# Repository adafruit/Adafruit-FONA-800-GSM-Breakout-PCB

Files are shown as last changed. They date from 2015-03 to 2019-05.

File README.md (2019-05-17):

# Adafruit FONA 800 GSM Breakout PCBs
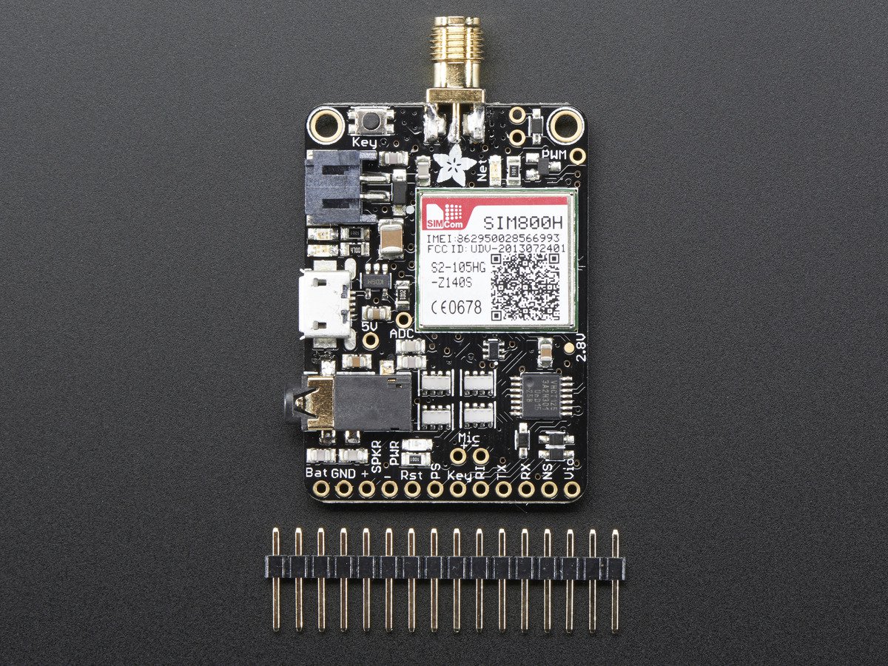
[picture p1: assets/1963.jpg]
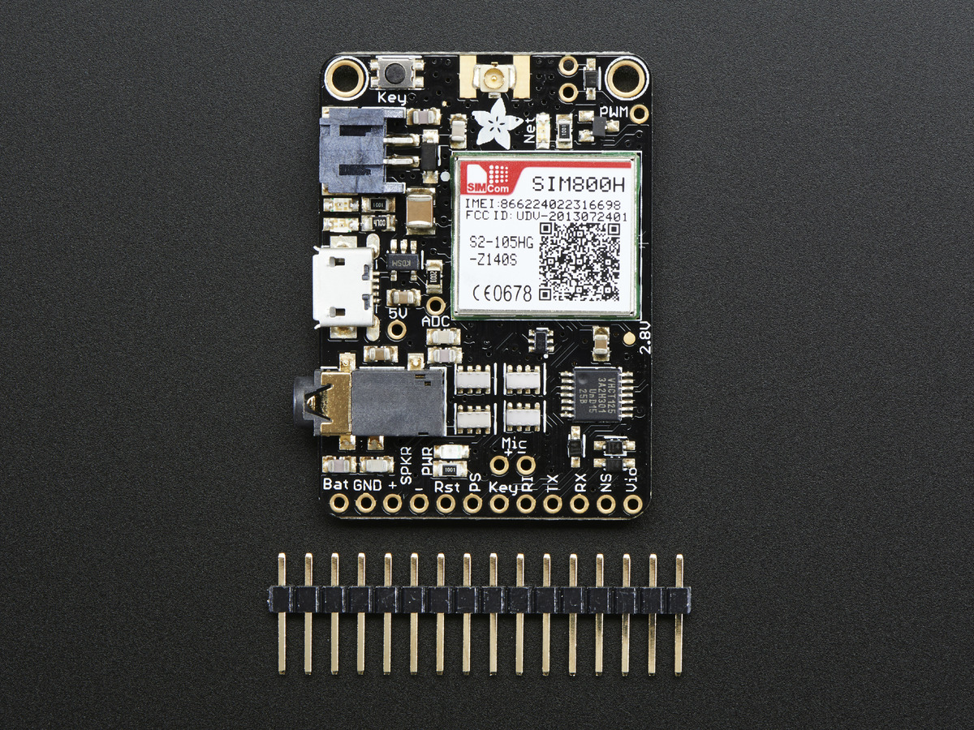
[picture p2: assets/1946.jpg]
&nbsp; <br />
Click to purchase from the Adafruit Shop:
- [Adafruit FONA - Mini Cellular GSM Breakout - SMA Version - v1](https://www.adafruit.com/product/1963)
- [Adafruit FONA - Mini Cellular GSM Breakout uFL Version](https://www.adafruit.com/product/1946)

This module measures only 1.75"x1.25" but packs a surprising amount of technology into its little frame. At the heart is a GSM cellular module (we use the latest SIM800) the size of a postage stamp. This module can do just about everything. One version has an SMA connector, the other has a uFL connector.

Quad-band 850/900/1800/1900MHz - connect onto any global GSM network with any 2G SIM (in the USA, T-Mobile is suggested)
- Make and receive voice calls using a headset OR an external 8Ω speaker + electret microphone
- Send and receive SMS messages
- Send and receive GPRS data (TCP/IP, HTTP, etc.)
- Scan and receive FM radio broadcasts (yeah, we don't exactly know why this was included but it works really well)
- PWM/Buzzer vibrational motor control
- AT command interface with "auto baud" detection

PCB files for the Adafruit FONA 800 GSM Cellular Breakouts. The format is EagleCAD schematic and board layout
- https://www.adafruit.com/products/1963
- https://www.adafruit.com/products/1946

### License

Adafruit invests time and resources providing this open source design, please support Adafruit and open-source hardware by purchasing products from [Adafruit](https://www.adafruit.com)!

All text above must be included in any redistribution

Designed by Limor Fried/Ladyada for Adafruit Industries.
Creative Commons Attribution/Share-Alike, all text above must be included in any redistribution. 
See license.txt for additional information.

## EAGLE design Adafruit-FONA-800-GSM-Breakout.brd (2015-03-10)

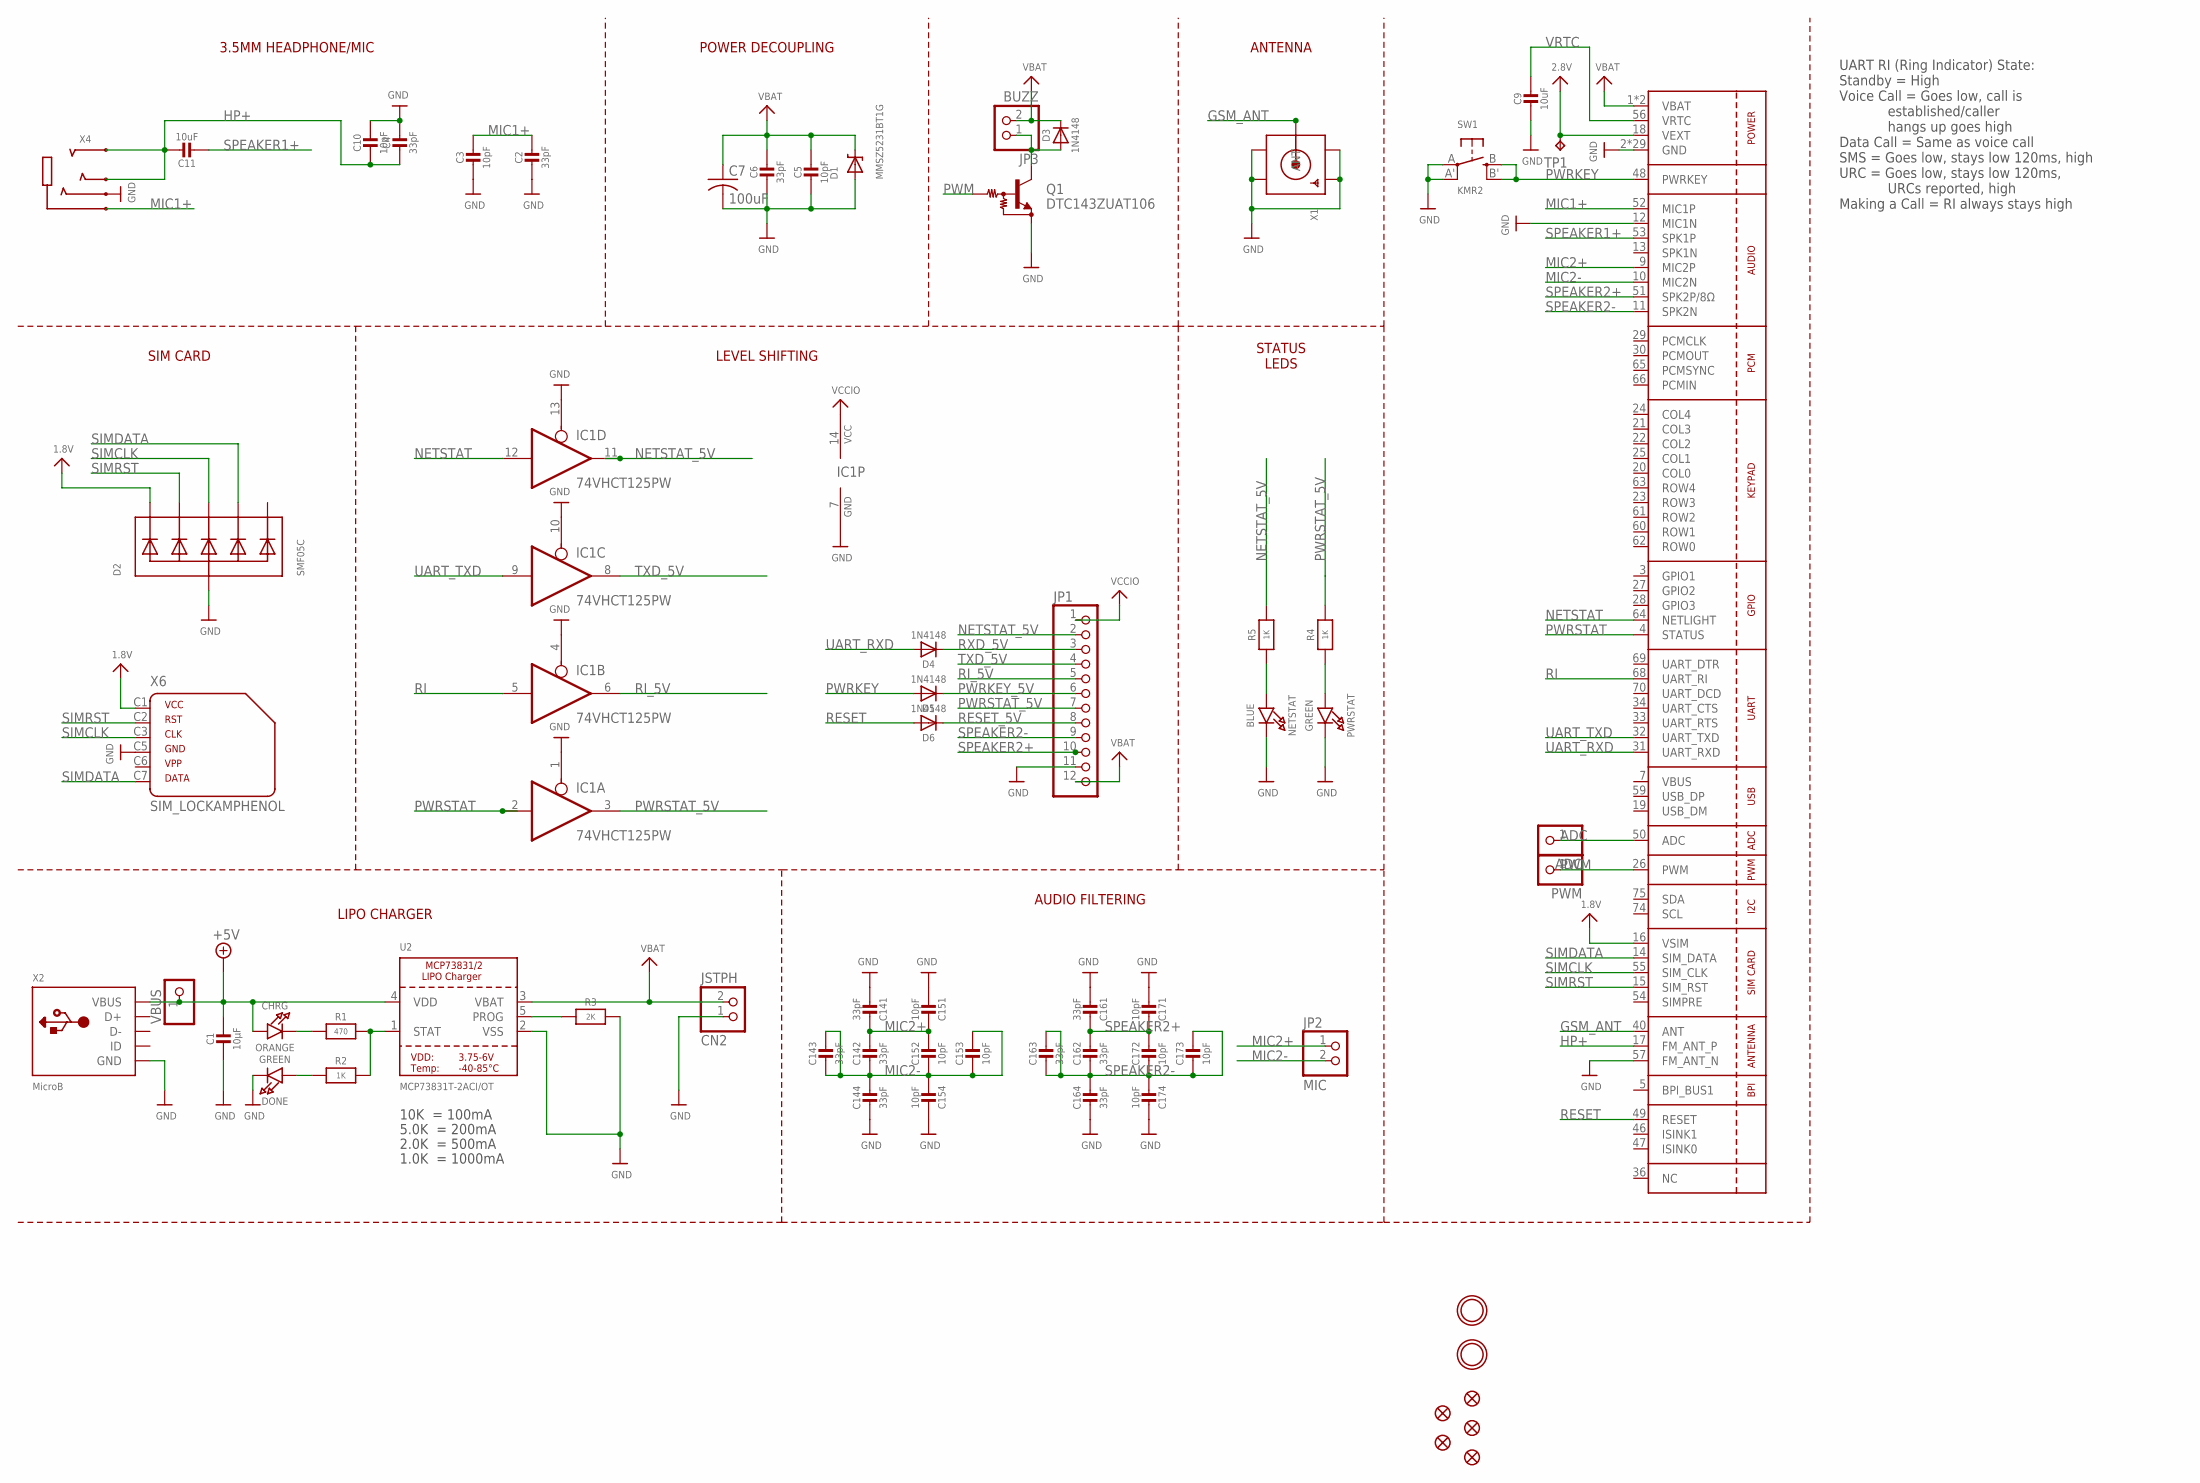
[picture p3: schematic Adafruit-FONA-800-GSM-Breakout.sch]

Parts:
ADC: PINHD-1X1CB; 1X01-CLEANBIG
C1: 10µF; 0805-NO
C2, C4, C6: 33pF; 0805-NO
C3, C5, C10: 10pF; 0805-NO
C7: 100uF; C1210
C9, C11: 10uF; 0805-NO
C14, C16: 33pF; RESPACK_4X0603
C15, C17: 10pF; RESPACK_4X0603
CHRG: ORANGE; CHIPLED_0805_NOOUTLINE
CN2: JSTPH; JSTPH2
D1: MMSZ5231BT1G; SOD-123
D2: SMF05C; SOT363
D3, D4, D5, D6: 1N4148; SOD-323
DONE: GREEN; CHIPLED_0805_NOOUTLINE
FID1, FID2, FID3, FID4, FID5: FIDUCIAL""; FIDUCIAL_1MM
IC1: 74VHCT125PW; TSSOP14
JP1: PINHD-1X12-CB; 1X12-CB
JP2: MIC; 1X02_ROUND
JP3: BUZZ; 1X02_ROUND
NETSTAT: BLUE; CHIPLED_0805_NOOUTLINE
PWM: PINHD-1X1CB; 1X01-CLEANBIG
PWRSTAT: GREEN; CHIPLED_0805_NOOUTLINE
Q1: DTC143ZUAT106; SC59-BEC
R1: 470; 0805-NO
R2, R4, R5: 1K; 0805-NO
R3: 2K; 0805-NO
SW1: KMR2; BTN_KMR2_4.6X2.8
TP1: TPTP11R; TP11R
U1: SIM800H/L; SIM800L
U2: MCP73831T-2ACI/OT; SOT23-5
U$33, U$34: MOUNTINGHOLE2.5; MOUNTINGHOLE_2.5_PLATED
VBUS: PINHD-1X1CB; 1X01-CLEANBIG
X1: SMACONNECTOR_EDGE_UFL; SMA_EDGELAUNCH_UFL
X2: MicroB; 4UCONN_20329
X4: AUDIO_3.5MMJACK_4POL; 4UCONN_18510
X6: SIM_LOCKAMPHENOL; C707_10M006_512_2

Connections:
1.8V: D2.1 (C1), U1.16 (VSIM), X6.C1 (1)
2.8V: TP1.TP, U1.18 (VEXT)
+5V: C1.1, CHRG.A, U2.4 (VDD), VBUS.1, X2.VBUS
ADC: ADC.1, U1.50 (ADC)
GND: C1.2, C2.2, C3.2, C4.1, C5.2, C6.2, C7.2, C9.2, C10.1, C14.5 (2), C14.8 (2), C15.4 (1), C15.8 (2), C16.5 (2), C16.8 (2), C17.4 (1), C17.8 (2), CN2.1, D1.A, D2.2 (A), DONE.C, IC1.1 (OE), IC1.4 (OE), IC1.7 (GND), IC1.10 (OE), IC1.13 (OE), JP1.11, NETSTAT.C, PWRSTAT.C, Q1.E, R3.2, SW1.A, SW1.A' (P1), U1.2 (GND), U1.6 (GND), U1.8 (GND), U1.12 (MIC1N), U1.35 (GND), U1.37 (GND), U1.38 (GND), U1.39 (GND), U1.41 (GND), U1.43 (GND), U1.44 (GND), U1.45 (GND), U1.57 (FM_ANT_N), U1.58 (GND), U1.67 (GND), U1.71 (GND), U1.72 (GND), U1.73 (GND), U1.76 (GND), U1.77 (GND), U1.78 (GND), U1.79 (GND), U1.80 (GND), U1.81 (GND), U1.82 (GND), U1.83 (GND), U1.84 (GND), U1.85 (GND), U1.86 (GND), U1.87 (GND), U1.88 (GND), U2.2 (VSS), X1.GND@1 (GND1), X1.GND@2 (GND2), X1.GND@3 (GND3), X1.GND@4 (GND4), X2.BASE@1 (GND), X2.BASE@2 (GND), X2.GND, X2.SPRT@1 (GND), X2.SPRT@2 (GND), X2.SPRT@3 (GND), X2.SPRT@4 (GND), X4.4-INNER_SLEEVE (RING1), X6.C5 (4)
GSM_ANT: U1.40 (ANT), X1.P (ANT)
HP+: C4.2, C10.2, C11.1, U1.17 (FM_ANT_P), X4.2-TIP (RING3), X4.3-OUTER_SLEEVE (RING2)
MIC1+: C2.1, C3.1, U1.52 (MIC1P), X4.1-GND (TIP)
MIC2+: C14.1, C14.2 (1), C15.1, C15.2 (1), JP2.1, U1.9 (MIC2P)
MIC2-: C14.3 (1), C14.4 (1), C14.6 (2), C14.7 (2), C15.3 (1), C15.5 (2), C15.6 (2), C15.7 (2), JP2.2, U1.10 (MIC2N)
unnamed: CHRG.C, R1.1
unnamed: R1.2, R2.2, U2.1 (STAT)
unnamed: PWRSTAT.A, R4.1
unnamed: R3.1, U2.5 (PROG)
unnamed: DONE.A, R2.1
unnamed: NETSTAT.A, R5.1
unnamed: D3.A, JP3.1, Q1.C
NETSTAT: IC1.12 (I), U1.64 (NETLIGHT)
NETSTAT_5V: IC1.11 (O), JP1.2, R5.2
PWM: PWM.1, Q1.B, U1.26 (PWM)
PWRKEY: D5.A, SW1.B (S), SW1.B' (S1), U1.48 (PWRKEY)
PWRKEY_5V: D5.C, JP1.6
PWRSTAT: IC1.2 (I), U1.4 (STATUS)
PWRSTAT_5V: IC1.3 (O), JP1.7, R4.2
RESET: D6.A, U1.49 (RESET)
RESET_5V: D6.C, JP1.8
RI: IC1.5 (I), U1.68 (UART_RI)
RI_5V: IC1.6 (O), JP1.5
RXD_5V: D4.C, JP1.3
SIMCLK: D2.4 (C3), U1.55 (SIM_CLK), X6.C3 (3)
SIMDATA: D2.5 (C4), U1.14 (SIM_DATA), X6.C7 (6)
SIMRST: D2.3 (C2), U1.15 (SIM_RST), X6.C2 (2)
SPEAKER1+: C11.2, U1.53 (SPK1P)
SPEAKER2+: C16.1, C16.2 (1), C17.1, C17.2 (1), JP1.10, U1.51 (SPK2P/8Ω)
SPEAKER2-: C16.3 (1), C16.4 (1), C16.6 (2), C16.7 (2), C17.3 (1), C17.5 (2), C17.6 (2), C17.7 (2), JP1.9, U1.11 (SPK2N)
TXD_5V: IC1.8 (O), JP1.4
UART_RXD: D4.A, U1.31 (UART_RXD)
UART_TXD: IC1.9 (I), U1.32 (UART_TXD)
VBAT: C5.1, C6.1, C7.1, CN2.2, D1.C, D3.C, JP1.12, JP3.2, U1.1 (VBAT), U1.42 (VBAT), U2.3 (VBAT)
VBUS: U1.7 (VBUS)
VCCIO: IC1.14 (VCC), JP1.1
VRTC: C9.1, U1.56 (VRTC)

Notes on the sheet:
10K = 100mA
5.0K = 200mA
2.0K = 500mA
1.0K = 1000mA
UART RI (Ring Indicator) State: Standby = High Voice Call = Goes low, call is established/caller hangs up goes high Data Call = Same as voice call SMS = Goes low, stays low 120ms, high URC = Goes low, stays low 120ms, URCs reported, high Making a Call = RI always stays high
ANTENNA
POWER DECOUPLING
3.5MM HEADPHONE/MIC
SIM CARD
LEVEL SHIFTING
LIPO CHARGER
AUDIO FILTERING
STATUS LEDS

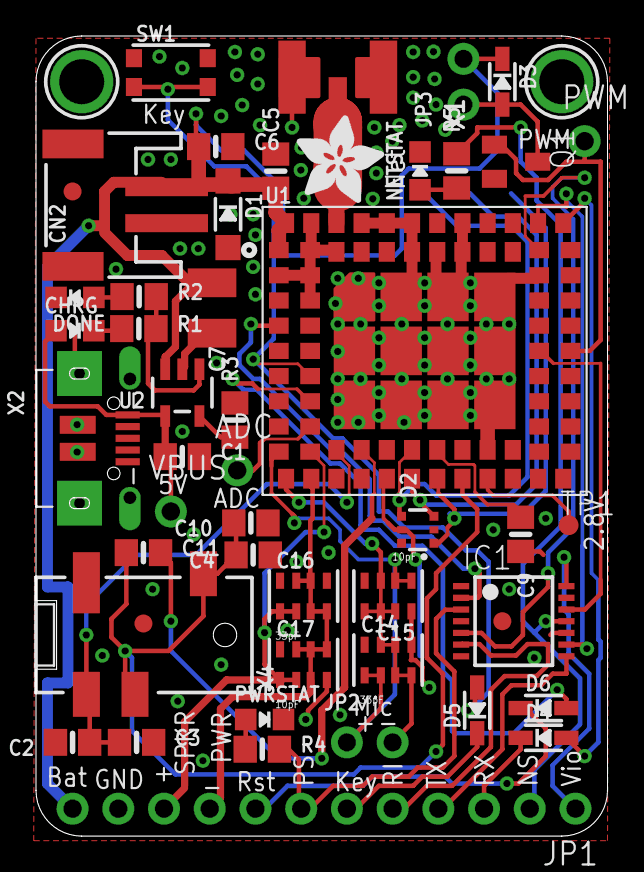
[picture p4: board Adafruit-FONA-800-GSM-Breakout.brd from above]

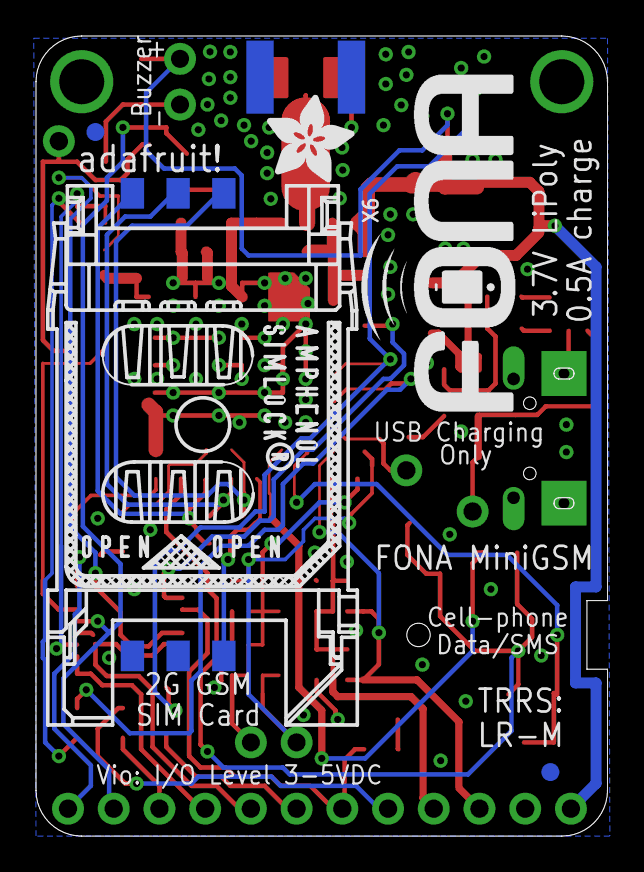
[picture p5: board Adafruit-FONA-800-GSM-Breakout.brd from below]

Board: 2 copper layers, 31.8 x 44.5 mm, 56 parts (5 on the bottom side), 41 nets.

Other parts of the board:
U$10, U$36: ADAFRUIT_5MM
U$26: FONA_LOGO

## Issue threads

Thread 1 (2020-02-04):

Need BOM for Adafruit-Fona-8-gsm-breakout-pcb

ghostcoffins, 2020-02-04:
Dear Sir/Madam,
I need Bills of material for this Adafruit-Fona-8-gsm-breakout-pcb. by doing my reasearch by looking at the schematic there is only one thing i cant understand are the 4xwhite 8 pin Points located near audio jack. if possible can someone provide me bom for this so that i can identify it

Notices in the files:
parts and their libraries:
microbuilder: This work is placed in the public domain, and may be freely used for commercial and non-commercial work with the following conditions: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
